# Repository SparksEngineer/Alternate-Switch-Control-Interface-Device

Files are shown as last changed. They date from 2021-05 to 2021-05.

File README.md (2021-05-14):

# Alternate-Switch-Control-Interface-Device
This repository contains files to recreate a "Alternate Switch Control Interface Device" that was designed and built to give the disabled individuals a cheap alternative to use their External Switch control universally to any smart device with the switch control accessibility feature.
To go to our step by step instructions to re-create the product go to https://www.instructables.com/Alternate-Switch-Control-Interface-With-USB-Cable-/

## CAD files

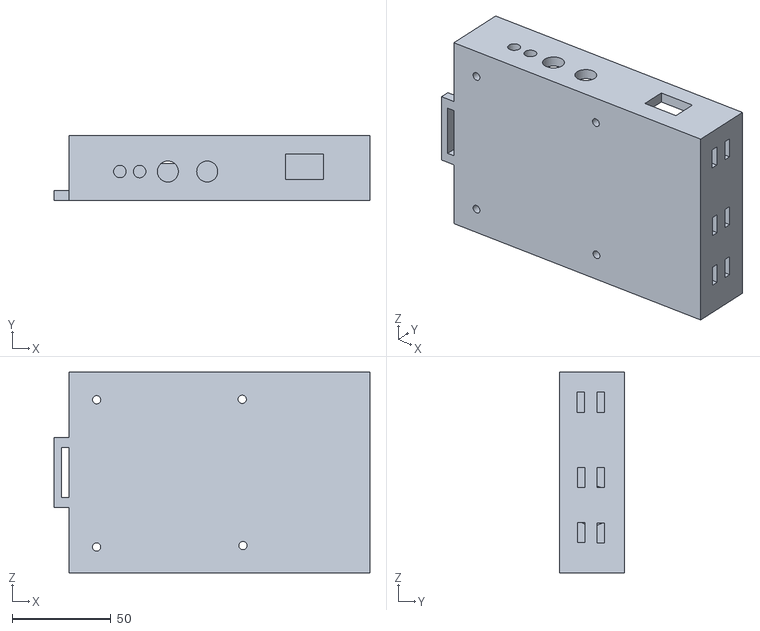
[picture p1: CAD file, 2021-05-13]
3D model STL files/Main box.stl
160.0 x 33.0 x 101.6

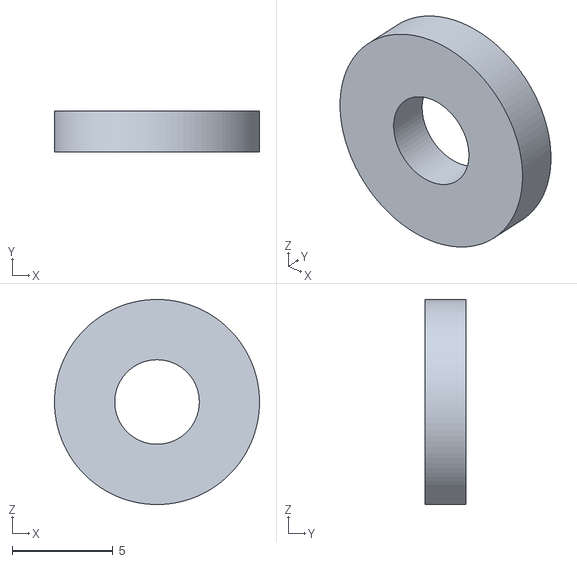
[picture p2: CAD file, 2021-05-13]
3D model STL files/Tiny spacer.stl
10.2 x 2.03 x 10.2

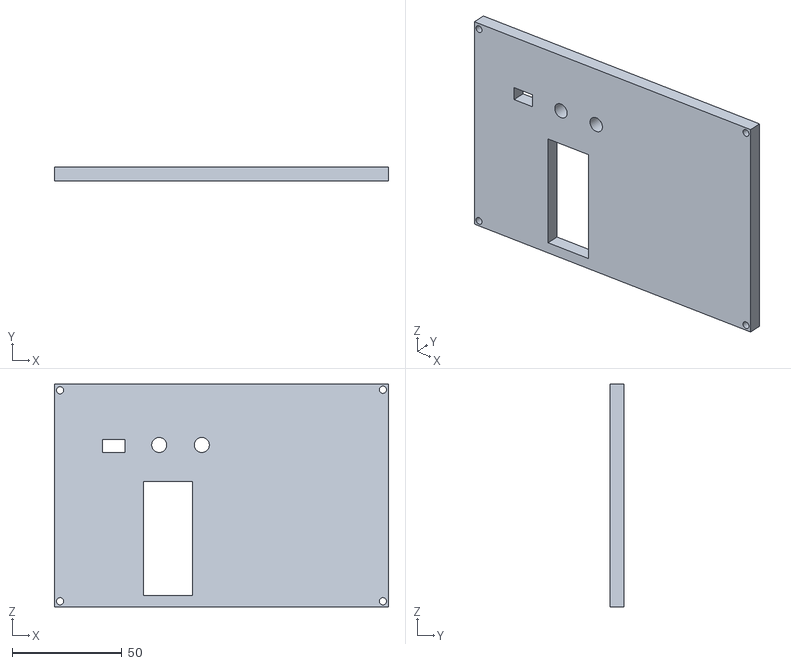
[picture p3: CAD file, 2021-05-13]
3D model STL files/Lid v2.stl
152.4 x 6.35 x 101.6

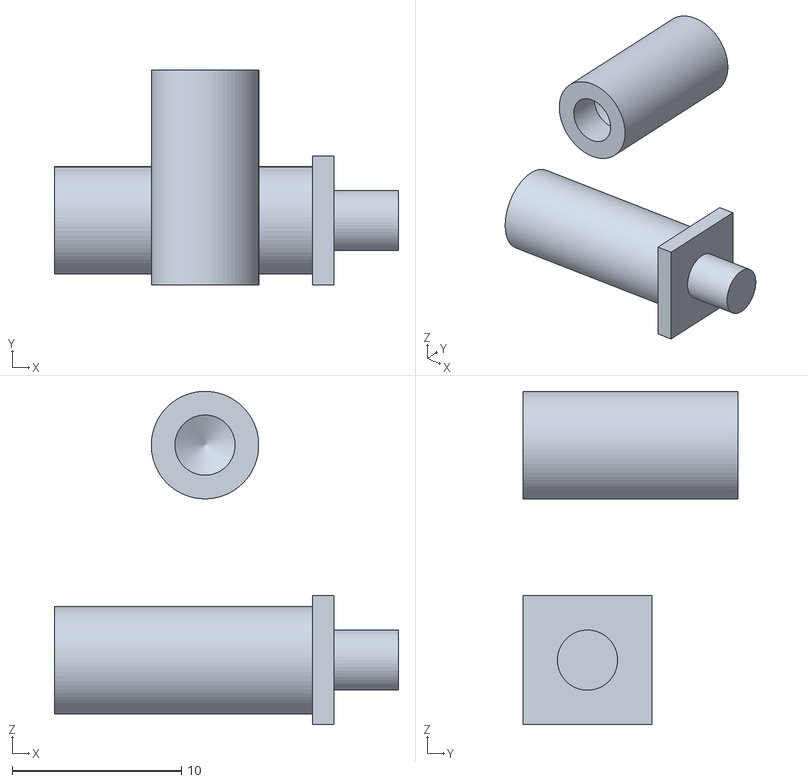
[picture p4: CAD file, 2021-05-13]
3D model STL files/button extender v9.stl
20.3 x 12.7 x 19.7

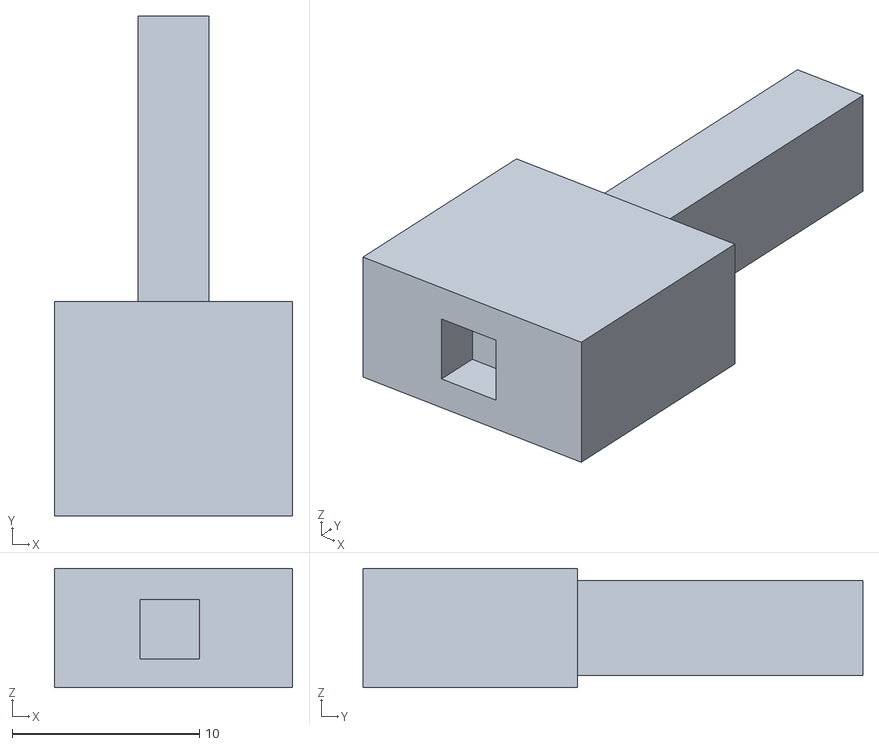
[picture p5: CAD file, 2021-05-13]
3D model STL files/switch extender v5.stl
12.7 x 26.7 x 6.35

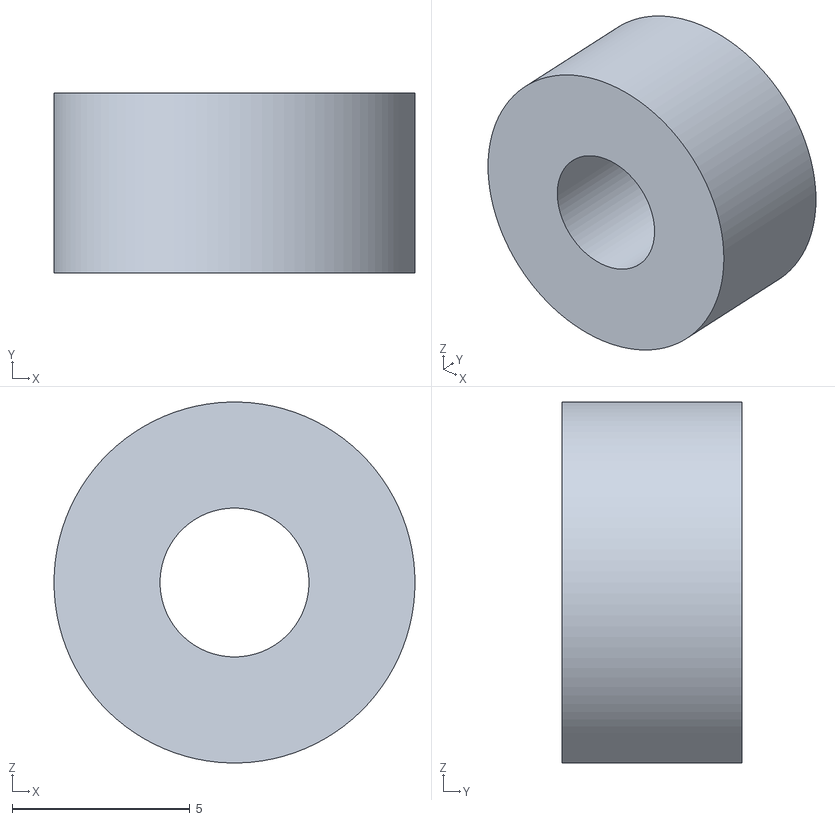
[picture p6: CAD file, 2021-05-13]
3D model STL files/Big spacer v5.stl
10.2 x 5.08 x 10.2

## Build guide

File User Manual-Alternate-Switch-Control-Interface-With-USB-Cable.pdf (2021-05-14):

User Manual

### Alternate Switch Control Interface

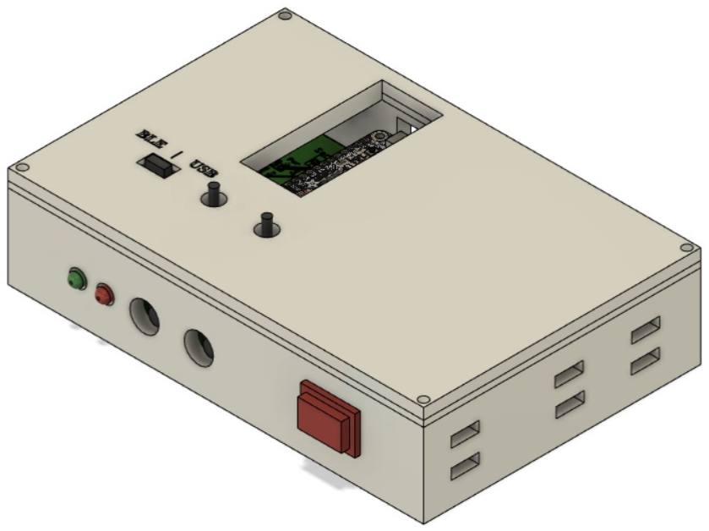
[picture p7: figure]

Product designed by:
Juan G. Lastra Febles
Jessica M. Torres Figueroa Gerardo L. Morales Torres
Carlos J. Morales Sandoval

### User Manual Index

Introduction: | 3
Figures: | 3
Specifications: | 5
Battery Specifications: | 5
Microcontroller Specifications: | 5
Main Box Specifications: | 6
Lid specifications: | 7
Product’s Instructions: | 8
Mode Select Switch | 8
BLE Mode; | 8
USB Mode: | 8
Battery Mode: | 8
Power Switch (ON/OFF Switch) | 9
Battery Level Indicator | 9
Charging the battery | 10
Product’s Components | 11
3.5mm External Switch Inputs Jacks | 11
Buttons | 11
External Switches Inputs Indicators (Green LED) | 12
Belt Fastener | 12
Warnings: | 12

## Introduction:

Please read this User Manual carefully, and take note of all the warnings before using the “Alternate Switch Control Interface” product. This manual aims to instruct the users on how to use the External Switch Control Interface that was created. The product was designed for people with physical disabilities who use an “External Adaptive Switch” as a means to use their electronics devices. This product provides them with a tool that enables them to use their “External Adaptive Switch” with any smart electronic devices such as smartphones, tablets, computers and any other electronic device that has the Switch Control accessibility feature available with either Bluetooth® or USB capability.

## Figures:

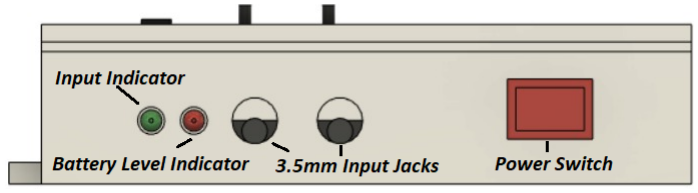
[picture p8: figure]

Figure 1: Front View of the Product

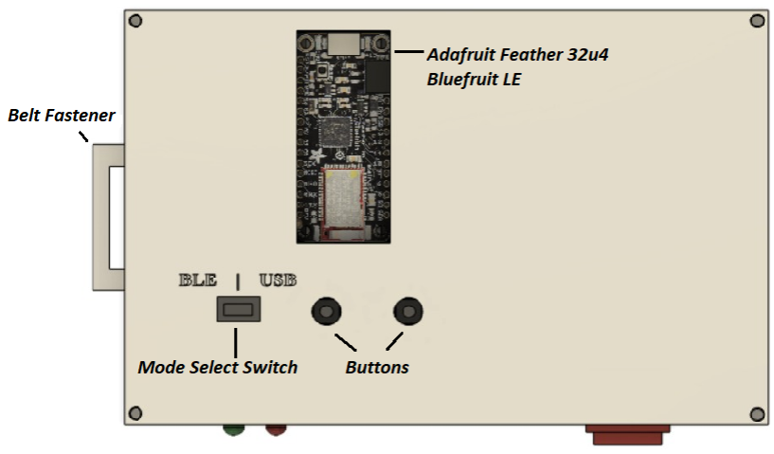
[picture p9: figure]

Figure 2: Top View of the Product

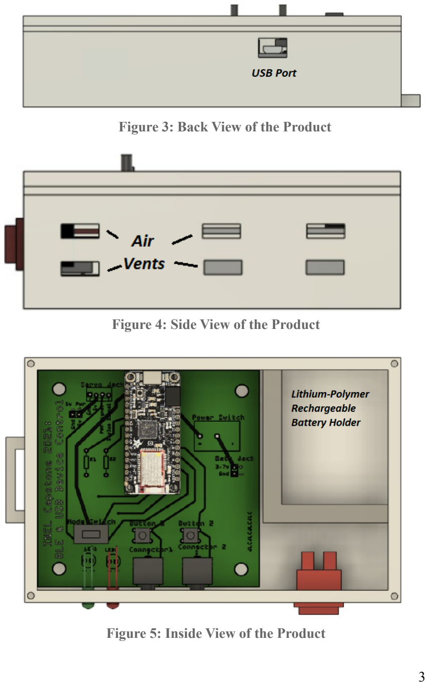
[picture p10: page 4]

Figure 3: Back View of the Product

Figure 4: Side View of the Product

Figure 5: Inside View of the Product

## 1. Specifications:

The “Alternate Switch Control Interface” product has the capability to connect via Bluetooth® or USB to any modern electronic device. This section of the manual will explain the specifications and limitations of the product that the user may wish to know.
- The device has the capability to connect via Bluetooth® Low Energy technology to any modern device that has Bluetooth® 4.0 onwards capability.
- The device when paired will act as an HID (Human Interface Device) Bluetooth® Keyboard with only two keys, the “w” and spacebar keys.
- The necessary Micro-USB cable is not included with the product, and must be a communication compatible USB cable. If the connected cable is meant to only charge devices, then it is only useful for charging the Battery of the product and “USB Mode” will not work.
- The product has been successfully tested with iOS, Android and computer devices.
- The whole product weighs 378.0 grams (or 0.83 pounds).

## ❖Battery Specifications:

- The product includes a rechargeable Ni-Cd battery, with 1000mAh and 3.7v capacity.
- The battery may last from 22.5 to 60 hours depending on its use.
- Approximate charging time is 7.5 hours when using the product’s USB port.
- Battery must not reach a temperature of 50°C (122°F), or the battery may become damaged.

## ❖Microcontroller Specifications:

This product currently uses an “Adafruit Feather 32u4 Bluefruit LE” microcontroller unit (MCU). Which is an Arduino IDE programming compatible MCU, with an integrated Bluetooth® Low Energy (BLE) module, built in Micro-USB port, and other specifications that were not used for this product. Some of its more technical specifications from the adafruit website https://www.adafruit.com/product/3379 are;
- Weights 5.7 grams
- Measures 51mm x 23mm x 8mm (2.0" x 0.9" x 0.28"), without headers soldered in.
- Atmel's low-power 8-bit AVR RISC-based microcontroller “ATMega32U4” @ 8MHz with 3.3V logic/power
- Bluetooth® Low Energy module is an “nRF51822” chipset from Nordic
- USB native support, with USB bootloader and serial port debugging
- Built in 100mA charging capability for any connected rechargeable battery, with a yellow LED charging status indicator on the Microcontroller.
- Red and blue LEDs for indicating Bluetooth® pairing status on the Microcontroller.

## ❖Main Box Specifications:

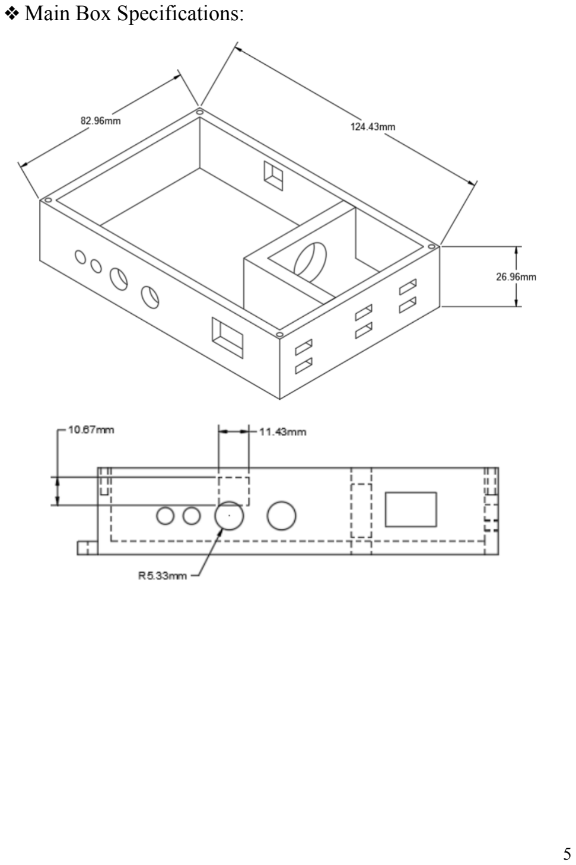
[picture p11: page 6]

## ❖Lid specifications:

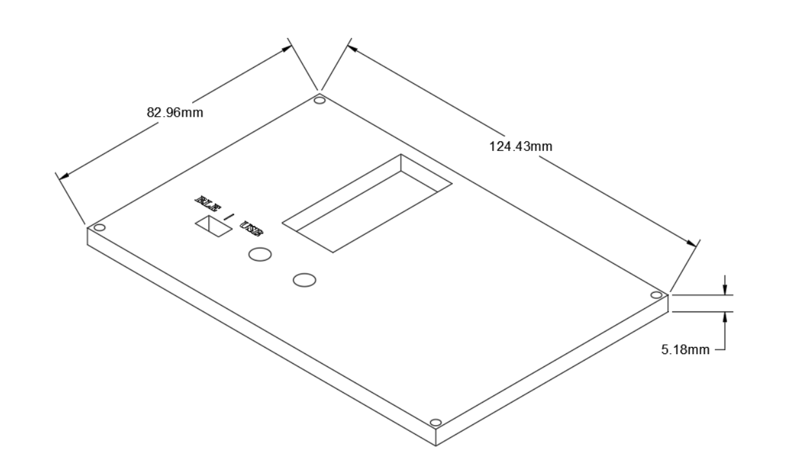
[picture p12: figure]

## 2. Product’s Instructions:

## ❖Mode Select Switch

The user may select what type of connection to use with the “Mode Select Switch” shown in Figure 2: Top View of the Product , and Figure 1: Front View of the Product. Depending on the position of this switch the user may connect the product to an electronic device via Bluetooth® (BLE Mode), USB cable (USB Mode), or just verify battery life (Battery Mode).
Note: When changing between the 3 available modes the product will still be paired with the smart device until disconnected on the user’s device.
- BLE Mode;
When the switch is aligned to the “BLE” text on the box (positioned to the left when looking at the product from the Top View or Front View), then the BLE mode will be enabled. When in BLE Mode the product will act as a Bluetooth® HID keyboard only.

The microcontroller includes a blue and red LED that the user can see through the small transparent window on the top of the box. Both the red and blue LEDs will be blinking when the device is ready to pair, and the blue LED will stay on when it is connected to a device.
- USB Mode:
When the switch is aligned to the “USB” text on the box (positioned to the far right when looking at the product from the Top View or Front View), then USB mode will be enabled. If in USB mode, the product will only work as an HID keyboard to a device when connected through a USB cable to the user’s device.

For USB mode to work with smart devices like smartphones and tablets (almost any small smart device that does not have the usual standard USB type A port), then the user must connect a USB cable from the Micro-USB port on the product, to the user's electronic device with the use of an adapter. If the user tries to connect the product directly with just a USB cable the smart device will not detect it, but this is not a problem if using a computer.
- Battery Mode:
When the switch is centered, Battery Mode is selected and the device will not transmit anything to the connected device, but will turn on the Red or Green LED depending on the battery status (please see the Battery Level Indicator section for more information).

## ❖ Power Switch (ON/OFF Switch)

The power switch will disconnect and reconnect the battery from the product’s circuitry when turned OFF or ON. This is optimum for when you wish to turn on and off the product, plus it is necessary for charging purposes. Take in mind the following;
- If the user will use the device in USB mode there is no need to turn the switch ON, because the external device will power the microcontroller. This applies to computers, smartphones, tablets or other electronic devices.
- We highly recommend that you turn the power switch to the OFF position if you are connected via USB to a smartphone, tablet or other small electronic device. Since this will try to recharge the rechargeable battery, and discharge the battery of the small electronic device.
- If you wish to use the device while connected to Bluetooth®, you need to turn the power switch to the ON position. Doing so will allow the rechargeable battery to power the microcontroller.
- The product battery may also be charged when in BLE mode by connecting a USB cable to the product and then to a power source (see Charging the battery section for more information), the product will continue to work on with the user’s device that was paired with.
- To charge the battery in the product, you will also need to turn the power switch to the ON position.

## ❖Battery Level Indicator

The “Alternate Switch Control Interface” product has a Green and Red LED, as seen in Figure 2: Front View of the Product. These LEDs are also used to indicate the battery status, but only when in “USB mode” or “Battery Mode” the battery
Note: If the product is charging or generally connected through the USB the LED indicators will NOT accurately state the status of the battery. The LED’s will also be unable to detect battery status if the power switch is OFF.
- Red LED will turn on and stay on when the battery level is lower than 25% . When this happens it is recommended to charge the battery soon.
- The Green LED will turn on and stay on when the battery level is higher than 25%, and have Although
- When in BLE Mode only the Red LED will turn on and stay on when the battery level is low. When in USB mode this Red LED will not turn on, since when the battery is charging it is difficult to accurately detect the battery levels.
- The Green LED will always flash ON everytime the user activates their external adaptive switch, or presses either of the test buttons, when in “USB Mode” or “BLE Mode”.

## ❖Charging the battery

The USB port is located at the back of the box (see Figure 3: Back View of the Product), and this port is also used to charge the product’s battery. Although the user must be wary of where they connect the other side of the USB cable when going to charge the battery.

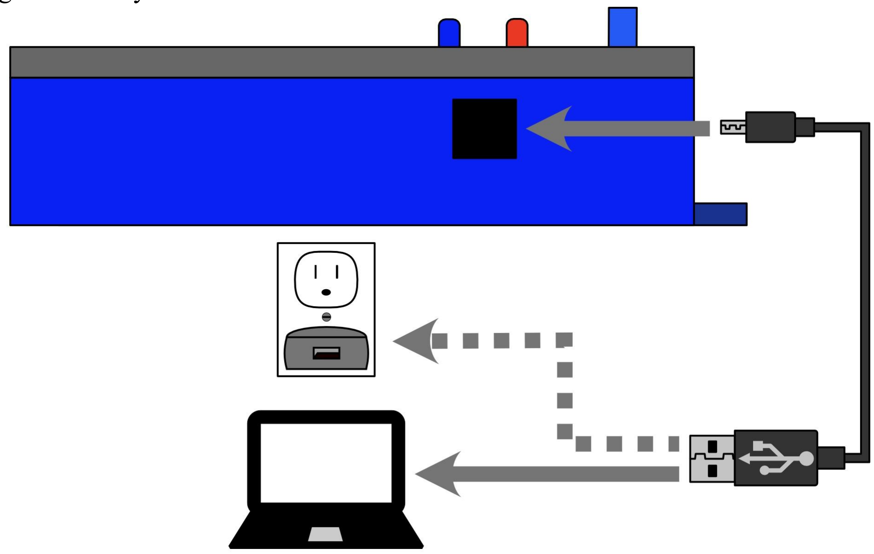
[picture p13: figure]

Figure 7: Illustration of how to charge device
- To charge the device’s battery, connect a Micro-USB cable to the USB port located in the back of the casing (see Figure 3: Back View of the Product) and insert the other end to a standard USB charging plug adapter, or computer.
- When the battery is charging the yellow LED on the microcontroller will turn on. The user can see this light through the small transparent window on top of the box (see Figure 2: Top View of the Product).
- Do not use a smartphone, tanbet or any other small capacity electronic device to charge the battery. Since it will discharge the battery of the small electronic device quickly, and may damage the user’s device’s battery. (which is why we instruct to turn the power switch to the Off position when in “USB Mode”)
- The battery should last at least 22.5 hours of continuous use, but could last up to 60 hours depending on the use.
- If the Red LED battery indicator on the front of the product is on, charge the battery for up to 7.5 hours. It should be fully charged then.
- You must leave the Power Switch ON when charging the battery, and otherwise when in USB mode keep it in the OFF position.
- The user can charge the battery and use the device in Bluetooth® mode at the same time. Note: the user may only charge the battery and use the “USB mode” if it is connected to a computer or any other big capacity device.

## 3. Product’s Components

## - 3.5mm External Switch Inputs Jacks

- The device brings the capability for connecting up to two External Adaptive Switches that use the standard 3.5mm cable plug. The user can connect their external switches to either or both input jacks called Connector #1 and Connector #2.
- The Input Jack to the left, when looking at the front of the box,, is known as Connector #1 , and is programmed to send a “w” key press as an HID Keyboard in either BLE or USB Mode.
- The Input Jack to the right, when looking at the front of the box,, is known as Connector #2 , and is programmed to send a spacebar key press as an HID Keyboard in either BLE or USB Mode.
- Set up the Switch Control accessibility feature in your device depending on which switch you use and how. Long Press will also be detected, but must be set up on the user’s device.

## - Buttons

- There are two buttons in the top of the box, one for each input jack. These are designed for the caretaker to test if the device is working properly.
- The buttons can also be used to control the device using the Switch control Feature. When either button is pressed they will send a key press signal corresponding to either Connector#1 or Connector #2, just as if an external adaptive switch is being used.
- The button on the left of the box, when looking at the front of the box, is known as Button #1 , and is programmed to send a “w” key press as an HID Keyboard in either BLE or USB Mode.
- The button to the right of the box, when looking at the front of the box, is known as Button #2 , and is programmed to send a spacebar key press as an HID Keyboard in either BLE or USB Mode.

## - External Switches Inputs Indicators (Green LED)

- Green LED turns on when a user's input is registered by either the two external switches inputs or buttons. It lets the user know that the signals are getting read by the microcontroller.

## - Belt Fastener

- The Belt Fastener seen in Figure 3: Top View of the Product is designed to be a type of handle, designed for strapping down the device with any Hook-and-loop fasteners, or hook-and-pile fasteners (often referred to just as velcro straps).

## 4. Warnings:

⚠ Do NOT let the electronics inside the product get wet.
⚠ Do NOT let the battery in the product become too hot when in use.
⚠ The Ni-Cd rechargeable battery must NOT reach a temperature of 50°C (122°F). ⚠ Do Not use if any conducting material (i.e. metal staples) are inside the product’s casing, as this may cause a short circuit and damage the circuitry.
⚠ Never leave the battery charging continuously for more than 7.5 hours.
⚠ When connecting the product to a smartphone or tablet with a USB cable, the user must use a USB adapter. In general if the electronic device does not have the standard USB connector (USB-A) then an adapter is needed, or the product will not work.
⚠ When in “USB mode” and using a smart device make sure to turn the power switch “OFF”.

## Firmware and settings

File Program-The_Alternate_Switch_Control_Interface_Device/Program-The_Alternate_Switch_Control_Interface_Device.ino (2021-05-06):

/*********************************************************************
  This program was created from an example for the nRF51822 based
  Adafruit Bluefruit LE modules. Like the Feather 32u4 Bluefruit LE,
  and the Feather M0 Bluefruit LE.

  Check out our instructable to understand the code more
  and learn about the circuit and components used for this project

  MIT license, check LICENSE for more information
  All text above, and the splash screen below must be included in
  any redistribution
*********************************************************************/
#include <Arduino.h>
#include <SPI.h>
#include "Adafruit_BLE.h"
#include "Adafruit_BluefruitLE_SPI.h"
#include "Adafruit_BluefruitLE_UART.h"

#include "BluefruitConfig.h"
#include "Keyboard.h"

#if SOFTWARE_SERIAL_AVAILABLE
#include <SoftwareSerial.h>
#endif
/*=========================================================================
    APPLICATION SETTINGS

      FACTORYRESET_ENABLE       Perform a factory reset when running this sketch
     
                                Enabling this will put your Bluefruit LE module
                              in a 'known good' state and clear any config
                              data set in previous sketches or projects, so
                                running this at least once is a good idea.

    MINIMUM_FIRMWARE_VERSION  Minimum firmware version to have some new features
    -----------------------------------------------------------------------*/
#define FACTORYRESET_ENABLE         0
#define MINIMUM_FIRMWARE_VERSION    "0.6.6"
//    #define MODE_LED_BEHAVIOUR          "MODE"//used for BLE UART communication
/*=========================================================================*/
//Setting up what kind of BLE hardware the Micontroler has
Adafruit_BluefruitLE_SPI ble(BLUEFRUIT_SPI_CS, BLUEFRUIT_SPI_IRQ, BLUEFRUIT_SPI_RST);


//Constants that won't change. They're used here to set pin numbers:
/**In the the Feather32u4 A1=D19, and in the Feather M0 A1=D15**/
const int GreenLED = 15;//GREEN LED connected to pin A1
const int RedLED = 16;//RED LED connected to pin A2
const int VBATPIN = 9;//Vatpin is A7 or D9 for Feather 32u4

const int SWITCH1 = 12; // Mode 1 switch (Left most setting)
const int SWITCH2 = 11; //Mode 2 switch (Right most setting)
const int BUTTON1 = 10;// Digital pin 10
const int BUTTON2 = 17;//A3 is Digital pin 21 for Feather 32u4
//For the Feather M0 the A3 is Digital pin 17
//Setting wait time that will make sure button signal is good
const int NoBounceDelayTime = 200;//Quick delay in microseconds

/**** Variables that must be intitiated but will change values ****/
//For saving Status of mode switch:
int SwitchState1 = 0; // variable for reading the Mode Switch status
int SwitchState2 = 0; // variable for reading the Mode Switch status
int CurrentSwitch1State = 0;
int CurrentSwitch2State = 0;
int LastSwitch1State = 0;
int LastSwitch2State = 0;

//Variables to save time in milliseconds (used for debuuging):
unsigned long Button1TotalTime = 0;//Will save total pressed time of Button1
unsigned long Button1PressedTime1 = 0;//Will save first time Button1 is pressed
unsigned long Button1PressedTime2 = 0;//Will save last time Button1 is pressed

unsigned long Button2TotalTime = 0;//Will save saving total pressed time of Button2
unsigned long Button2PressedTime1 = 0 ;//Will save first time Button1 is pressed
unsigned long Button2PressedTime2 = 0;//Will save last time Button1 is pressed

void error(const __FlashStringHelper*err) {
  Serial.println(err);
  while (1);
}
//code lines that are run only once are put here
void setup() {
  //Initializing or setting Up Communication for MCU;
  //  while (!Serial);
  Serial.begin(115200);//Initialize Serial Communication at a 115200 Baud Rate
  Keyboard.begin();// initialize keyboard communication: (aka set control over keyboard)

  Serial.println(F("Adafruit Bluefruit HID Keyboard Example"));
  Serial.println(F("---------------------------------------"));

  /* Initialise the module */
  Serial.print(F("Initialising the Bluefruit LE module: "));

  if ( !ble.begin(VERBOSE_MODE) )
  {
    error(F("Couldn't find Bluefruit, make sure it's in CoMmanD mode & check wiring?"));
  }
  Serial.println( F("OK!") );

  if ( FACTORYRESET_ENABLE )
  {
    /* Perform a factory reset to make sure everything is in a known state */
    Serial.println(F("Performing a factory reset: "));
    if ( ! ble.factoryReset() ) {
      error(F("Couldn't factory reset"));
    }
  }
  /* Disable command echo from Bluefruit */
  ble.echo(false);

  Serial.println("Requesting Bluefruit info:");
  /* Print Bluefruit information */
  ble.info();
  /* Change the device name to make it easier to find */
  Serial.println(F("Setting device name to 'Bluefruit Keyboard': "));
  if (! ble.sendCommandCheckOK(F( "AT+GAPDEVNAME=Bluefruit Keyboard" )) ) {
    error(F("Could not set device name?"));
  }

  /* Enable HID Service */
  Serial.println(F("Enable HID Service (including Keyboard): "));
  if ( ble.isVersionAtLeast(MINIMUM_FIRMWARE_VERSION) )
  {
    if ( !ble.sendCommandCheckOK(F( "AT+BleHIDEn=On" ))) {
      error(F("Could not enable Keyboard"));
    }
  } else
  {
    if (! ble.sendCommandCheckOK(F( "AT+BleKeyboardEn=On"  ))) {
      error(F("Could not enable Keyboard"));
    }
  }
  /* Add or remove service requires a reset */
  Serial.println(F("Performing a SW reset (service changes require a reset): "));
  if (! ble.reset() ) {
    error(F("Couldn't reset??"));
  }
  // Initializing the button pin as an input with Pullup resistor (HIGH when not pressed logic):
  pinMode(VBATPIN, INPUT);
  pinMode(BUTTON1, INPUT_PULLUP);//"HIGH"(ON) until pressed, then "LOW"(OFF)
  pinMode(BUTTON2, INPUT_PULLUP);//"HIGH"(ON) until pressed, then "LOW"(OFF)

  // Initialize the SWITCH  pin as an input:
  pinMode(SWITCH1, INPUT_PULLDOWN);//"LOW"(OFF) until "pressed", then goes to "HIGH"(ON)
  pinMode(SWITCH2, INPUT_PULLDOWN);//"LOW"(OFF) until "pressed", then goes to "HIGH"(ON)
  pinMode(GreenLED, OUTPUT);//RED LED
  pinMode(RedLED, OUTPUT);//GREEN LED
}
/*********************************************************************
  Mode 1 = Switch is to the left. As such BLE keyboard mode
  Mode 2 = Switch is to the right. As such USB Keyboard mode
  Mode 0 = Switch is Centered. As such the BATTery voltage is sent to device as text
*********************************************************************/
void loop() {
  // Read the of the Switch value, and reset LastSwitch1State to LOW:
  LastSwitch1State = 0;
  LastSwitch2State = 0;
  CurrentSwitch1State = digitalRead(SWITCH1); //save the state of switch 1st pin (the most left)
  CurrentSwitch2State = digitalRead(SWITCH2); //save the state of switch last pin (the most right)
  /***********************************************************************/
  // Note to self for Button/Switch States:
  //     Buttons are "HIGH" until pressed, then they got to LOW
  //     Switch pin is "LOW" until moved/activated, then they got to HIGH
  /***********************************************************************/

  //************************** Mode 1, Bluetooth Keyboard mode **************************/
  while (digitalRead(SWITCH1) == HIGH) { //While Multi Mode Switch is to the Left (pin 12 is ON) stay in "Mode 1"
    CurrentSwitch1State = digitalRead(SWITCH1);
    CurrentSwitch2State = digitalRead(SWITCH2);

    /***If statement to send Serial msg only once to Serial monitor***/
    if ((CurrentSwitch1State == 1) && (LastSwitch1State == 0))
    {
      Serial.println("Mode 1, BLE mode");//Send Serial.print line once
      LastSwitch1State = CurrentSwitch1State;//save that the last state is now 1 so we don't go into this loop
      delay(100);//very small wait
    }

    /******** Start the actual code for Mode 1 *********/
    //------Section for when Button 1 is pressed------
    if (digitalRead(BUTTON1) == LOW) {//if button1 is pressed
      delay(NoBounceDelayTime);//Quick delay to make sure keypress is not sent twice
      digitalWrite(GreenLED, HIGH);//Turn ON Green LED

      Serial.println("Button 1 was pressed");
      //      //Save at what time the button was 1st pressed
      //      Button1PressedTime1 = millis();//save at what time the button was 1st pressed

      /****Send "w" keypress without releasing the key yet****/
      ble.println("AT+BLEKEYBOARDCODE=00-00-1A");//Sending code for "w" key which is 0x1A in HEX
      //The "Long Press" feature is included with this while loop
      while (digitalRead(BUTTON1) == LOW) { //while button is still pressed wait
        Serial.println("Button 1 looong press");
        //        //Save at what time the button was last pressed
        //        Button1PressedTime2 =  millis();
      }
      /*The following lines are to send debugging msgs to the serial monitor only*/
      //      if (Button1PressedTime2 > Button1PressedTime1) { //only if time 2 is larger than time1
      //        Button1TotalTime = Button1PressedTime2 - Button1PressedTime1;//calculate total spent time
      //        Serial.print("Button1 Total Time pressed: ");
      //        Serial.println(Button1TotalTime);
      //      }
      //      Button1TotalTime = 0;//reset the time counted

      /**** Release all pressed keys ****/
      ble.println("AT+BLEKEYBOARDCODE=00-00");//Indicating that to release all the keys
      delay(NoBounceDelayTime);//Small wait to make sure "switch bouncing" effect is stopped
    }//End loop for pressing Button 1

    //------Section for when Button 2 is pressed------
    if (digitalRead(BUTTON2) == LOW) {//if button2 is pressed
      delay(NoBounceDelayTime);//Small wait to make sure "switch bouncing" effect is stopped
      digitalWrite(GreenLED, HIGH);//Turn ON Green LED
      Serial.println("Button 2 was pressed");

      //      //Save at what time the button was 1st pressed
      //      Button2PressedTime1 = millis();//save at what time the button was 1st pressed

      //****Send "w" keypress without releasing****/
      ble.println("AT+BLEKEYBOARDCODE=00-00-2C");//Sending code for "w" key which is 0x1A in HEX

      //The "Long Press" feature is included with this while loop
      while (digitalRead(BUTTON2) == LOW)//while button is still pressed
      {
        Serial.println("Button 2 looong press");
        //        Button2PressedTime2 =  millis();//save at what time the button was pressed
      }
      /*The following lines are to send debugging msgs to the serial monitor only*/
//      Button2TotalTime = Button2PressedTime2 - Button2PressedTime1;//calculate total spent time
//      if (Button2PressedTime2 > Button2PressedTime1) { //only if time 2 is larger than time1
//        Serial.print("Button2 Total Time pressed: ");
//        Serial.println(Button2TotalTime);
//      }
//      Button2TotalTime = 0;//reset the time counted
//      //**** Release all pressed keys ****/
      ble.println("AT+BLEKEYBOARDCODE=00-00");//Indicating that to release all the keys
      delay(NoBounceDelayTime);//Small wait to make sure "switch bouncing" effect is stopped
    }//End loop for pressing Button 2
    
    else { //if a button is not pressed keep Green LED off
      digitalWrite(GreenLED, LOW);//Green LED off
    }

    float measuredvbat = analogRead(9);
    measuredvbat *= 2;    // we divided by 2, so multiply back
    measuredvbat *= 3.3;  // Multiply by 3.3V, our reference voltage
    measuredvbat /= 1024; // convert to voltage
    Serial.print("VBat: " );
    Serial.println(measuredvbat);

    //when voltage value is LOW
    if (measuredvbat < 3.4) {
      digitalWrite(RedLED, HIGH);//Turn ON Red LED
    }
    //when voltage value is High
    if (measuredvbat > 3.6) {
      digitalWrite(RedLED, LOW);//Turn Off Red LED
    }
    
  }//end of Mode 1 (when SwitchState1 is HIGH/ON)

  /**************************************Mode 2, USB Keyboard mode**************************************/
  while (digitalRead(SWITCH2) == HIGH) { //While Multi Mode Switch is to the right (pin 11 is ON) stay in "Mode 2"
    CurrentSwitch1State = digitalRead(SWITCH1);
    CurrentSwitch2State = digitalRead(SWITCH2);

    /***If statement to send Serial msg only once to Serial monitor***/
    if ((CurrentSwitch2State == 1) && (LastSwitch2State == 0))//If loop to send Serial.print once
    {
      Serial.println("----Mode 2, USB mode ON----");//when done print this msg once
      //save that the last state is 1 so we don't go into this loop
      LastSwitch2State = CurrentSwitch2State;
      delay(100);//small wait
    }

    /***** Start the actual code for Mode 2 ******/
    //**Section for when Button 1 is pressed, Short Press and Long Press included with while loop****/
    if (digitalRead(BUTTON1) == LOW) {//if button1 is pressed
      delay(NoBounceDelayTime);//Small wait to make sure "switch bouncing" effect is stopped
      digitalWrite(GreenLED, HIGH);//Turn ON LED
      Serial.println("Button 1 was pressed");

      //Save at what time the button was 1st pressed
      Button1PressedTime1 = millis();//save at what time the button was 1st pressed

      //****Send "w" keypress without releasing****/
      Keyboard.press(119);//Sending code for "w" key which is 119 in ASCII

      while (digitalRead(BUTTON1) == LOW)//while button is still pressed
      {
        Serial.println("Button 1 looong press");
        //        Button1PressedTime2 = millis();//save at what time the button was pressed
      }
      /*The following lines are to send debugging msgs to the serial monitor only*/
      //      if (Button1PressedTime2 > Button1PressedTime1) { //only if time 2 is larger than time1
      //        Button1TotalTime = Button1PressedTime2 - Button1PressedTime1;//calculate total spent time
      //        Serial.print("Button1 Total Time pressed: ");
      //        Serial.println(Button1TotalTime);
      //        Button1TotalTime = 0;//reset the time counted
      //      }
      //**** Release all pressed keys ****/
      Keyboard.releaseAll();//Lets go of all keys currently pressed
      delay(NoBounceDelayTime);//Small wait to make sure "switch bouncing" effect is stopped
    }//End loop for pressing Button 1

    /******Section for when Button 2 is pressed, Short Press and Long Press included with while loop****/
    if (digitalRead(BUTTON2) == LOW) {//if Button2 is pressed
      delay(NoBounceDelayTime);//Small wait to make sure "switch bouncing" effect is stopped
      digitalWrite(GreenLED, HIGH);//Turn ON LED

      Serial.println("Button 2 was pressed");
      //      //Save at what time the button was 1st pressed
      //      Button2PressedTime1 = millis();

      //****Send "spacebar" keypress without releasing****/
      Keyboard.press(32);//Sending code for "spacebar" key which is 32 in ASCII

      /**Serial Print lines are for debugging only, they may be commented out*/
      while (digitalRead(BUTTON2) == LOW) {//Wait in loop while button is still pressed
        Serial.println("Button 2 looong press");
        //        Button2PressedTime2 = millis();//save at what time the button was pressed
      }
    }//End loop for pressing button 2
    else {
      //if no button is pressed keep LED off
      digitalWrite(GreenLED, LOW);
    }
    /*The following lines are to send debugging msgs to the serial monitor only*/
    //            if (Button2PressedTime2 > Button2PressedTime1) { //only if time 2 is larger than time1
    //              Button2TotalTime = Button2PressedTime2 - Button2PressedTime1;//calculate total spent time
    //              Serial.print("Button2 Total Time pressed: ");
    //              Serial.println(Button2TotalTime);
    //              Button2TotalTime = 0;//reset the time counted
    //            }
    /**** Release all pressed keys ****/
    Keyboard.releaseAll();//Lets go of all keys currently pressed
  }//End of Mode 2
  /**************************************Mode 0, Only Information Mode**************************************/
  //While Multi Mode Switch is Centered (OFF) stay in "Mode 0"
  while ((digitalRead(SWITCH1) == LOW) && (digitalRead(SWITCH2) == LOW)) {
    CurrentSwitch1State = digitalRead(SWITCH1);
    CurrentSwitch2State = digitalRead(SWITCH2);

    if (((CurrentSwitch1State == 0) && (LastSwitch1State == 0)) || ((CurrentSwitch2State == 0) && (LastSwitch2State == 0))) {
      Serial.println("----Mode 0, Battery Mode ON----");//when done print this msg
      LastSwitch1State = 1;//save that the last state is now 1, so we don't go into this loop again ever again
      LastSwitch2State = 1;//save that the last state is now 1, so we don't go into this loop again ever again
    }
    float measuredvbat = analogRead(VBATPIN);
    measuredvbat *= 2;//Value was divided by 2 in MCU, so multiply back
    measuredvbat *= 3.3;// Multiply by 3.3V, our reference voltage
    measuredvbat /= 1024;// Convert Analog Input to a voltage
    Serial.print("VBat: " );
    Serial.println(measuredvbat);

        //when voltage value is LOW
        if (measuredvbat < 3.4) {
          digitalWrite(GreenLED, LOW);//Turn Green LED Off
          digitalWrite(RedLED, HIGH);//Turn red LED On
        }
        //when voltage value is HIGH
        if (measuredvbat > 3.6) {
          digitalWrite(GreenLED, HIGH);//Turn Green LED On
          digitalWrite(RedLED, LOW);//Turn red LED Off
        }
  }//end of Mode 0
}//END OF VOID LOOP

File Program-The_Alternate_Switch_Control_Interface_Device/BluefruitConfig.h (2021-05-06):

// COMMON SETTINGS
// ----------------------------------------------------------------------------------------------
// These settings are used in both SW UART, HW UART and SPI mode
// ----------------------------------------------------------------------------------------------
#define BUFSIZE                        128   // Size of the read buffer for incoming data
#define VERBOSE_MODE                   true  // If set to 'true' enables debug output


// SOFTWARE UART SETTINGS
// ----------------------------------------------------------------------------------------------
// The following macros declare the pins that will be used for 'SW' serial.
// You should use this option if you are connecting the UART Friend to an UNO
// ----------------------------------------------------------------------------------------------
#define BLUEFRUIT_SWUART_RXD_PIN       -1     // Required for software serial!
#define BLUEFRUIT_SWUART_TXD_PIN       -1    // Required for software serial!
#define BLUEFRUIT_UART_CTS_PIN         -1    // Required for software serial!
#define BLUEFRUIT_UART_RTS_PIN         -1   // Optional, set to -1 if unused


// HARDWARE UART SETTINGS
// ----------------------------------------------------------------------------------------------
// The following macros declare the HW serial port you are using. Uncomment
// this line if you are connecting the BLE to Leonardo/Micro or Flora
// ----------------------------------------------------------------------------------------------
#ifdef Serial1    // this makes it not complain on compilation if there's no Serial1
  #define BLUEFRUIT_HWSERIAL_NAME      Serial1
#endif


// SHARED UART SETTINGS
// ----------------------------------------------------------------------------------------------
// The following sets the optional Mode pin, its recommended but not required
// ----------------------------------------------------------------------------------------------
#define BLUEFRUIT_UART_MODE_PIN        -1    // Set to -1 if unused


// HARDWARE SPI SETTINGS
// ----------------------------------------------------------------------------------------------
// The following macros declare the pins to use for HW SPI communication.
// SCK, MISO and MOSI should be connected to the HW SPI pins on the Uno, etc.
// This should be used with nRF51822 based Bluefruit LE modules that use SPI.
// ----------------------------------------------------------------------------------------------
#define BLUEFRUIT_SPI_CS               8
#define BLUEFRUIT_SPI_IRQ              7
#define BLUEFRUIT_SPI_RST              4    // Optional but recommended, set to -1 if unused

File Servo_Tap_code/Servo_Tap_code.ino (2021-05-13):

///////////////////////////////////////////////////////////////////////
//  This code is to make the servo move from 45 to 90 degrees and     //
//  90 to 45 degrees with a press of a button. Also this code, once   //
//  the button is pressed will not move until pressed again.         //
//////////////////////////////////////////////////////////////////////

#include<Servo.h>

// defining the constant pins for the microcontroller 
#define ServoPin 9
#define button_pin 2

// This will be the the variable of the code
int button_pressed = LOW; // This is when the button is pressed is down
int Servo_angle = 0; // Setting the angle of the servo
Servo servo; // Making the Servo library into the variable servo


void setup() {
  // Setting up the code
  Serial.begin(115200);
  servo.attach(ServoPin); //This will attach the servo to the designded pin
  servo.write(45);
  pinMode(button_pin,INPUT_PULLUP); // This will help make the pin work using an internal resistance
  Serial.println("Servo on");
  
}

void loop() {
  // Making the loop for the servo movement form 45 to 90 degrees 
  
  if (digitalRead(button_pin) == button_pressed ){
        Servo_angle =90;
  }
  else {
       Servo_angle =45;
     
    }
      servo.write(Servo_angle);
  }

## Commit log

2021-05-06 Add files via upload
    This is the first upload of the Arduino IDE program for the Alternate Switch Control Interface Device Project
2021-05-13 Add files via upload
    All the STL file to 3D print the Container for the Alternate Switch Control Interface Product
    [Big spacer v5.stl, Lid v2.stl, Main box.stl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]
2021-05-13 Add files via upload
    This File contains the program to control a servo with a stylus atached
2021-05-14 Add files via upload
    User Manual for the Alternate Switch Control Interface Product
